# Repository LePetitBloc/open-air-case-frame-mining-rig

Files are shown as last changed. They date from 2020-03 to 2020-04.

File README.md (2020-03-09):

# Stackable aluminium open air case frame for GPU Mining Rig
This DIY minercase was made with simplicity in mind. It is made from aluminum angle bar that can be found in any hardware store.

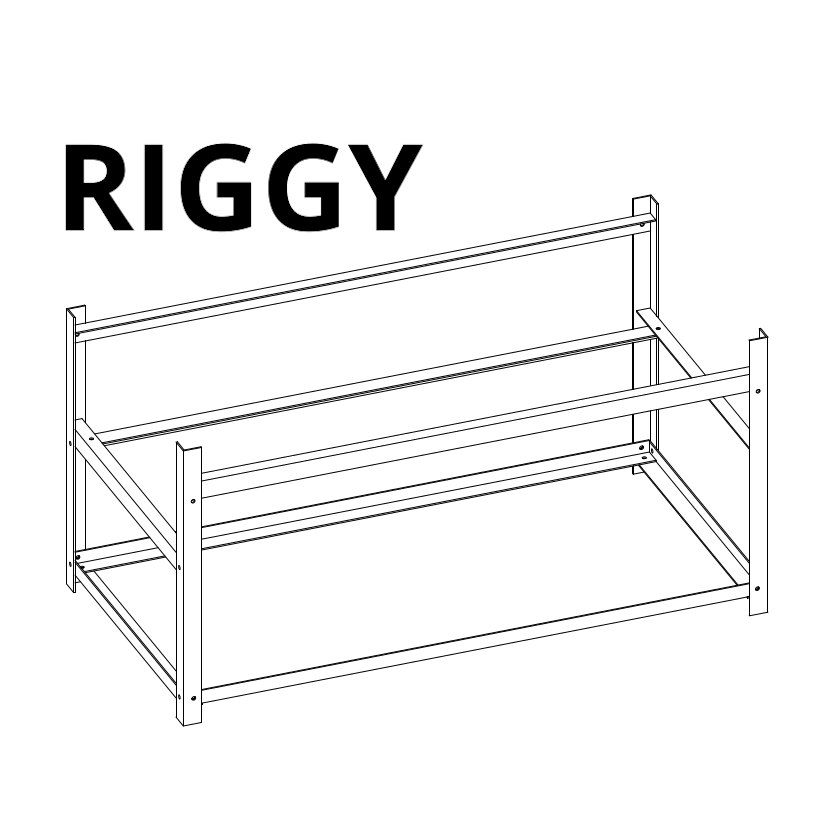
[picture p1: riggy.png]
Riggy


## Cryptocurrencies

It wasn’t meant to mine any specific coin but it’s used in real life with 6 AMD RX570 2x600w PSU, mining Dagger hashimoto (ETH, ETC, …) and/or Cryptonite (XMR, ...) algorithms.

## Design

Aluminum is light, robust, durable and elegant. It is not very conductive, (and you could push that even further with anodized aluminum) and doesn’t retain heat. And keep the overall frame lightweight thus easy to move around.

The base design is open and keep space between your electronic components and graphic cards for better thermal dissipation and preventing them of interfering with each other for a quitter result. 
Reserved enough space for equipment overhaul enhancing the cooling and extending the lifespan of graphics cards 

The basic design dimension are as follow 640mm x 320mm x 320mm
> <3 round numbers :)

- **Dimensions** 640mm x 320mm x 320mm
- **Weight** ???
- **Material** aluminium. 
- **Color** silver

The design is modular and variations can be made :
- to fit high capacity
- as a shelf / rack
- adapted to 6, 8, 12 GPU

## CAD (Computer-aided design)

The conception was made with [Freecad](https://www.freecadweb.org/) but a few exports are available for other CAD softwares:
- STEP or IGES for **Solidworks**
- DWG for **AutoCad** or **Sketchup**

### Parameters
The rig as been parameterised in Freecad via a Spreadsheet for easier customization.
The following parameters are available:

Every piece of the frame are made of standard aluminium corners but you can change their characteristics depending on your findings:
**bar_thickness** 1.5mm
**bar_width** 20mm
**bar_height** 15mm
**graphic_card_length** 270mm
**graphic_card_height** 112mm
**width** 640mm
**height** 320mm
**bottom_empty_space** 20mm
**top_empty_space** 20mm
> You can easily switch these values from mm to inches
> For example of you’d like to fit 12 graphic cards instead of 6 you could simply raise the `width` of the design. 

- You could put 2 range of graphic cards or 1 range of graphic card with a double width design
- Could fit any kind of motherboard, graphic card, any kind of  hardware with the proper tweaks.
- It was tought for usage with 120mm fans but not a requirement.
- The design can be made stackable in two ways.
- If your planning from the start to fit many mining rig in the same design you need to double or triple the vertical bar and duplicate the design as many time as required.
- If it’s an afterthought process, just make another case and print this little 3D printed piece (we’re to call it the *joiner*) to maintain the cases together.

## Make

### Required tools
- rivet plier
- drill bit for aluminum (1 of )
- tap (to create threaded holes, to secure the graphic cards)
- metal saw

### Consumables
- 28  pop rivets - 4x10mm
- regular case screws
- spacers to secure your motherboard (usually shipped with any case, but can be found online, or scavenged from old cases)
> https://upload.wikimedia.org/wikipedia/commons/e/ef/Toennchen_IMGP5029_wp.jpg

This rig is only made of 2 types of aluminium angle bar:
- One with equal sides, from a profile view it would looks as this ⌟
- One with a shorter side, from a profile view it would looks as this  ｣
> https://www.bricodepot.fr/lyon-st-priest/corniere-en-aluminium-brut-l-250m-l-20mm-h-20mm-ep-15mm/prod1791/
> https://decines.entrepot-du-bricolage.fr/pr-corniere-egale-en-aluminium-anodise-15x15cm-couleur-argent-2-5m-rqdb020205-1089668,40917,71,332,794,1238.htm

> Here is a formula to calculate the total length of raw material required.
> length of ⌟ required =  4 * height
> length of ｣ required =  5 * width + 4 depth

> For example if the bars were sold by units of 2 meters each:
>You would need:
> ⌟
>4 * `unit_length`
> `sold_length`
> `number_of_bars_required`
> |`Sold_length` / 4 * `unit_length`|

### Manual

[The manual](manual.pdf) as other parts of the project is a work in progress...

### Bonuses
- To reduce vibrations you can create rubber washer out of old bike tires and a hollow hole punch for leather.
- There is a 3D printable *foot* `projects/foot.fcstd` that could be made out of soft plastic or rubber like material, but these kind of materials doesn’t come cheap unfortunately.

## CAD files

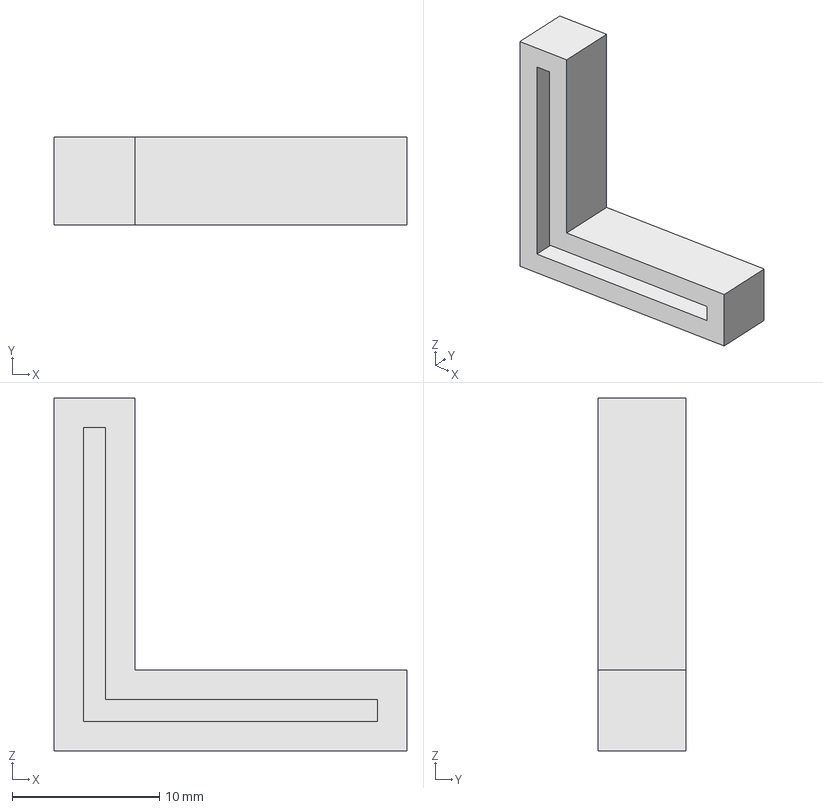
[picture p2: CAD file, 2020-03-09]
projects/foot.fcstd
24.0 x 6.00 x 24.0 mm

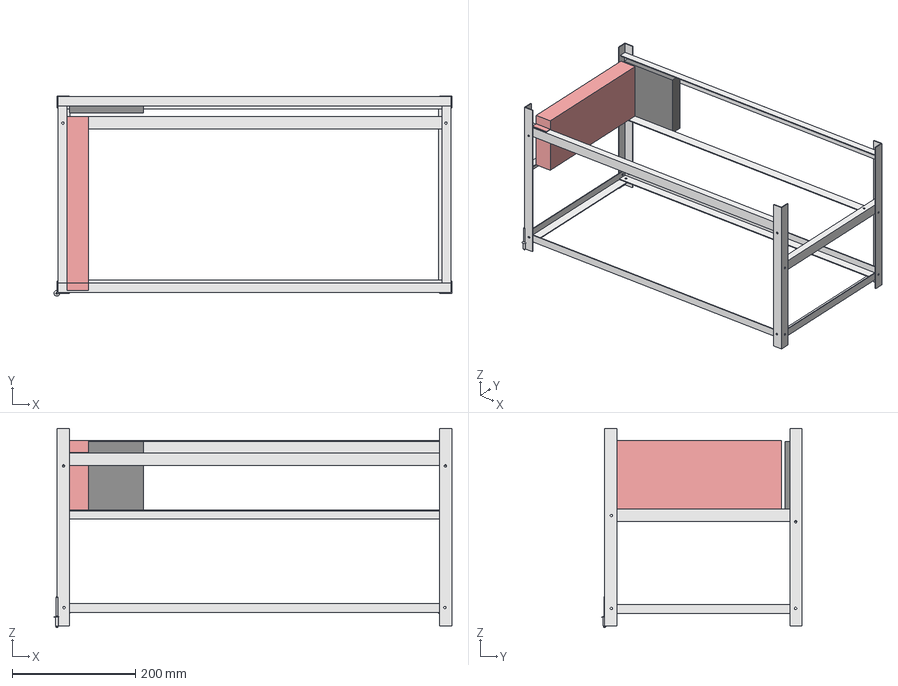
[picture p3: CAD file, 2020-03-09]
projects/open_air_case_frame.fcstd
644.7 x 324.7 x 322.8 mm
vertical_front_left_body
side_bottom_body
vertical_back_body
side_middle_body
bottom_body
top_front_body
cards_holder_body
fans_bar_body
left_middle_mirror
vertical_front_left_mirror
left_bottom_mirror
front_bottom_mirror
vertical_back_left_mirror
rivet
graphic_card_extrude
fan_extrude

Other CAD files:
exports/open_air_case_frame.iges
exports/open_air_case_frame.amf
exports/open_air_case_frame.obj

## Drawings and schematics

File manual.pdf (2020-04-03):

# RIGGY

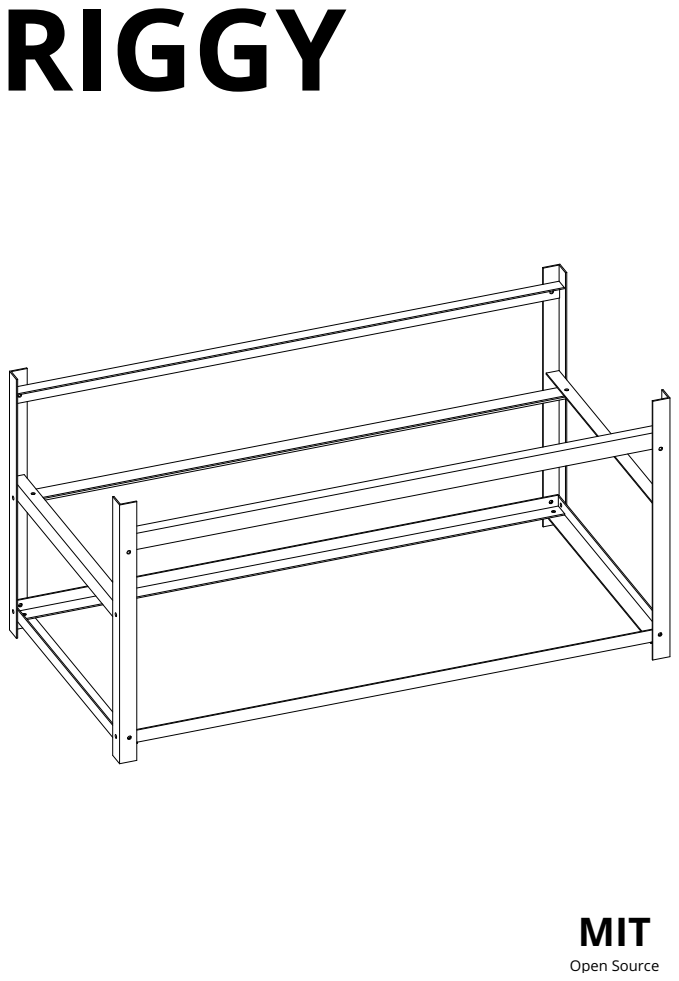
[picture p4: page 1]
MIT; Open Source

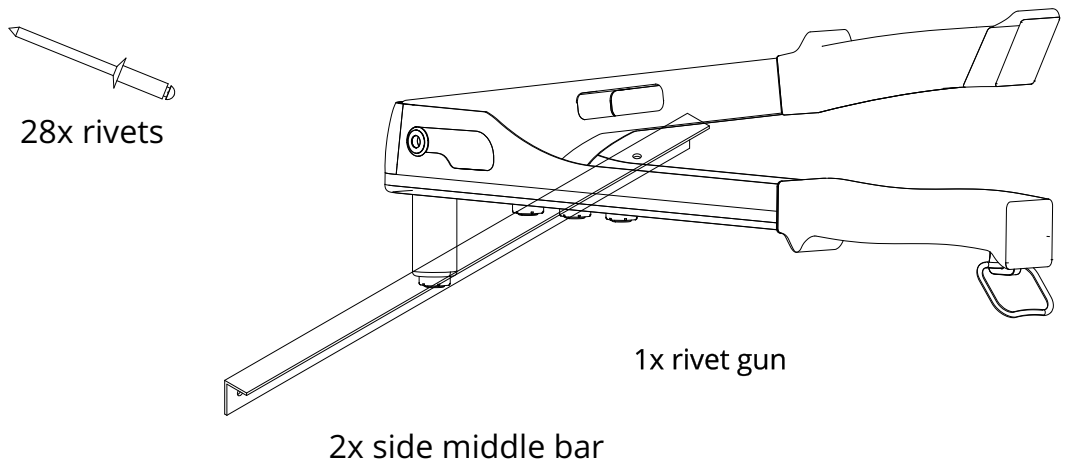
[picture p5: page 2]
28x rivets

2x side middle bar

1

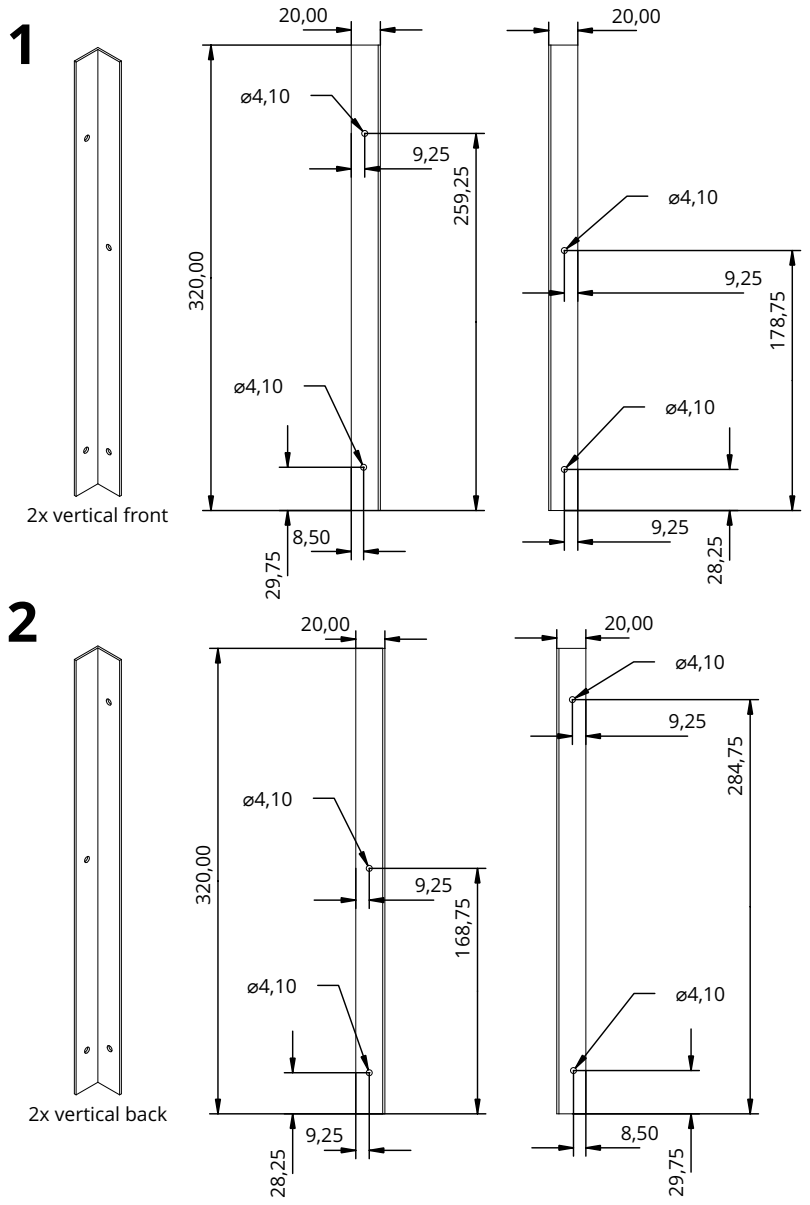
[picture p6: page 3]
2x vertical front; 2x vertical back

3

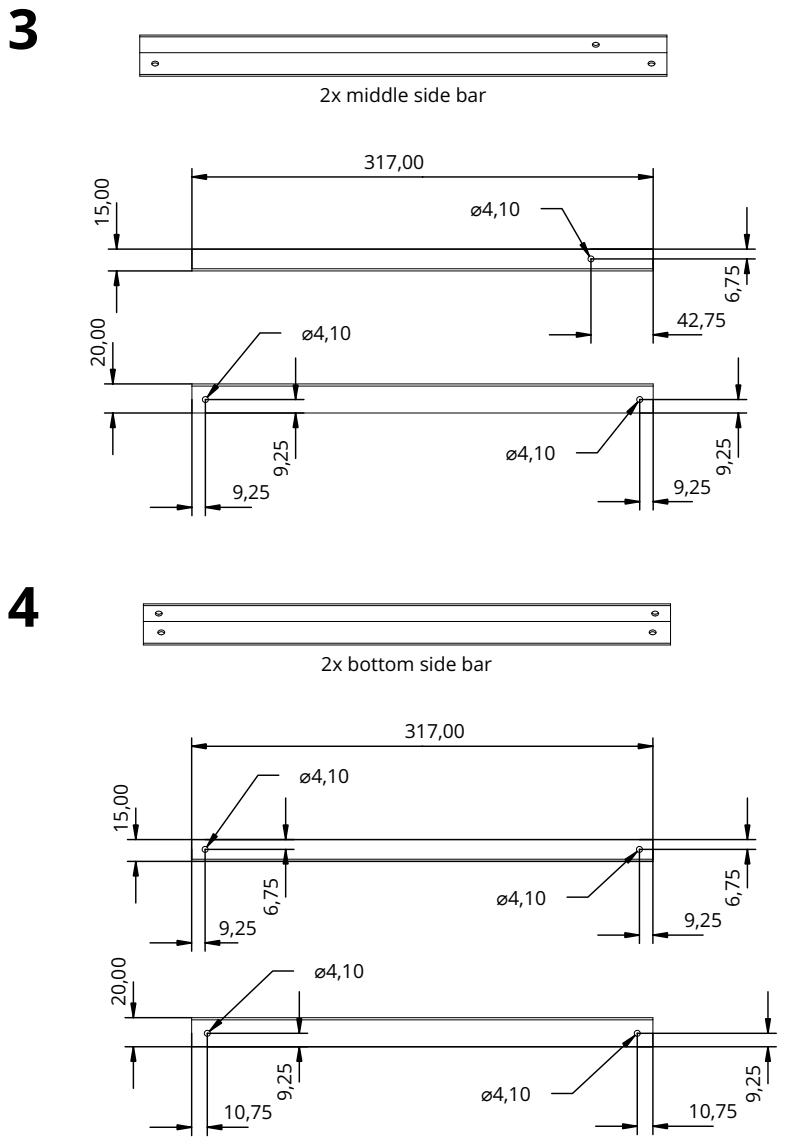
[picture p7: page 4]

2x middle side bar

2x bottom side bar

5

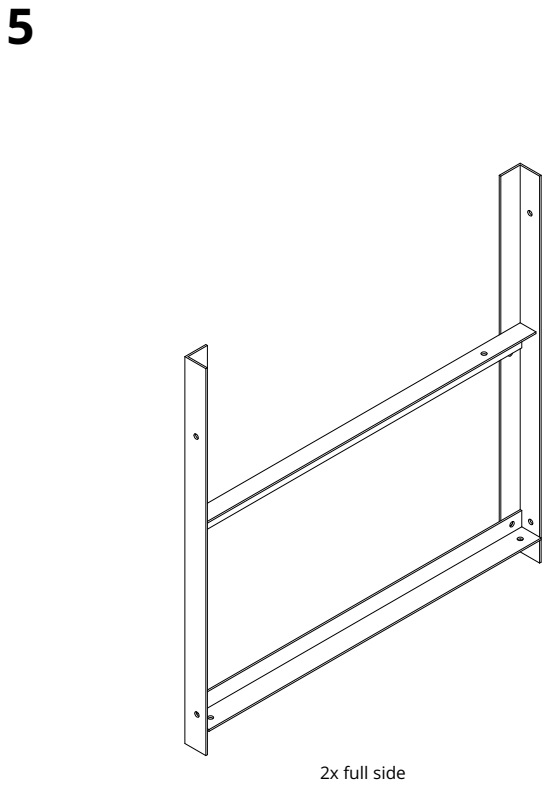
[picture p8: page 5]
2x full side

6

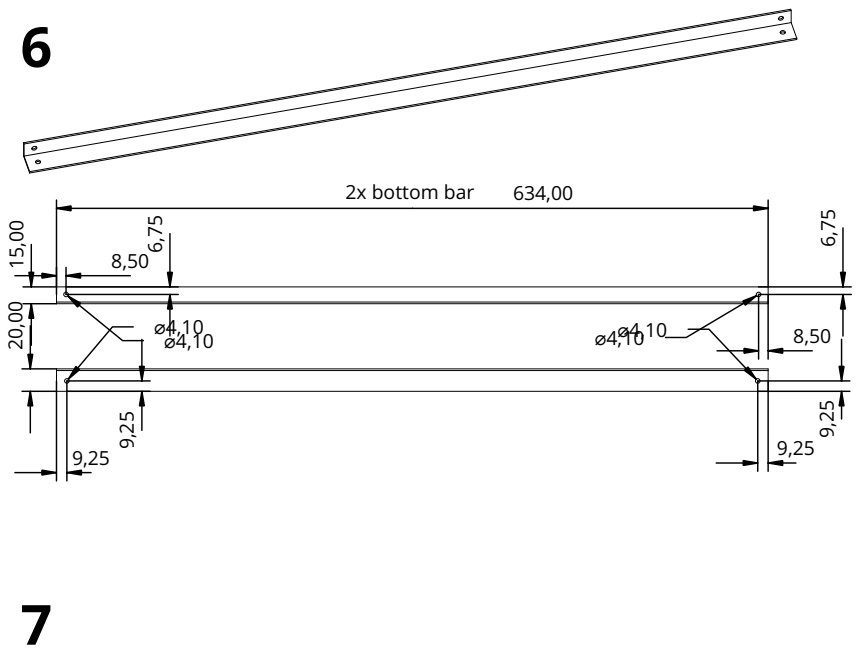
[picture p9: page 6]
2x bottom bar

89

10

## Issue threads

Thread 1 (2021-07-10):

Motherboard Attachment

infosisio, 2021-07-10:
Hi, great concept. What about attaching the motherboard? Commercial cases have a base with all the slots.

lutangar, 2021-07-12:
In our implementation the motherboard was screwed to [spacers](https://en.wikipedia.org/wiki/Spacers_and_standoffs) on the bottom bars.
Holes were made in the bars using a [tap](https://en.wikipedia.org/wiki/Tap_and_die#Tap) to create threaded holes.

I suppose some of these holes could be added to the design but it probably won't fit every motherboard.

... if I remember correctly we also added another bar at mid range, it also helped fitting the power supply.

I won't update the design but feel free to do so yourself.

Anyway here's a quick drawing to get a better idea:
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

> __See :__
> https://github.com/LePetitBloc/open-air-case-frame-mining-rig#consumables
> https://github.com/LePetitBloc/open-air-case-frame-mining-rig#required-tools
